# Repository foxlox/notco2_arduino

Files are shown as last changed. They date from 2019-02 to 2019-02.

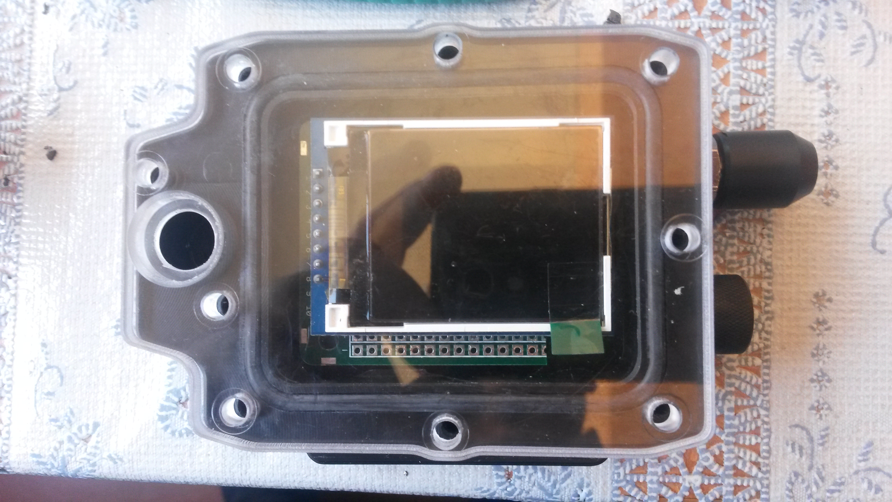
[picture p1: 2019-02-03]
docs/zzz_pics/wrist_enclosure_Sebastiano.jpg

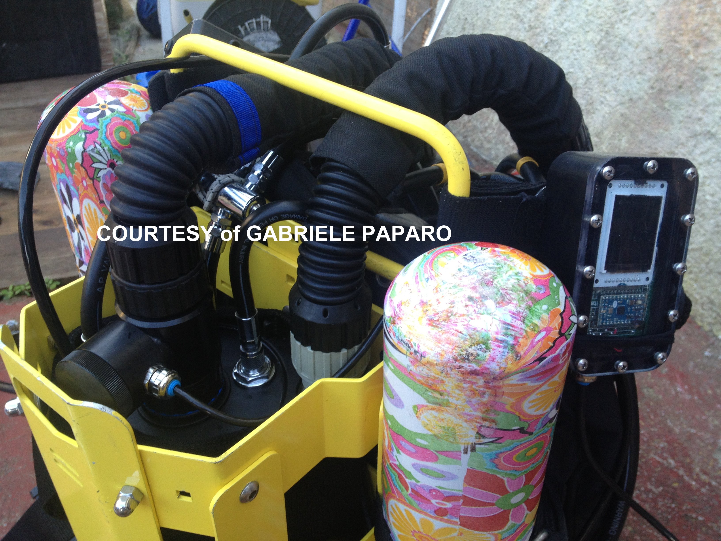
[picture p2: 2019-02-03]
docs/zzz_pics/photo(2).jpg

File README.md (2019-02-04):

NotCO2 - A Co2 analyzer for rebreathers
=======================================
fortunato lodari - fox@thebrain.net

If you wish to write me by email, please use the tag [NOTCO2] (with brackets)
in your subject

Please read all DOCs carefully

Project borns in 2011 by a personal need, I'm a mathematical, then I can't leave an independent variable to change my life for a sport.
This independent variable is Carbon Dioxide, CO2. Then I decided to begin a new project to analyze my breathe underwater.

Till today, me and other many peoples are using it with satisfaction by over 6 years.
The sensor is working good for an average life of 5 years.

I received a lot of offers for my project, but I wish to share this with other peoples who want to hack.

Please do not be surprised reading the source code, I'm really (but really!) much more professional and tidy
than you consider me to look at it, it's really simple. It was born to hack, and then when it worked 100% I left it as it is.

It bores me to refine it and I'll not do it just now
that I want to share it ;-)
Now it's your time to refine it, but remember: it really works very well!!!

Documents:

a. layout of PCB and project to build it

b. required hardware components

c. source code HUD (never optimized, discreetly legible, absolutely improvable...)

d. source code Wrist Console (also fot it never optimized, discreetly legible, absolutely improvable...)

e. all DGWs to build your own enclosures with a 3d lathe machine

f. some pics

About CO2 Sensor: I cannot include device's interface specification without owner authorization, but you could try to ask
them: Dynament Ltd - www.dynament.com

  The sensor doesn't suffer with moisture, it's important to stay face down in the loop, and to be dry after diving.

Please, read ALL documents in each folder.

The Author is not responsible for damage to peoples that use this project.
It works perfectly but you must build it perfectly too.

Special thanks to:

Gabriele Paparo for hints, support and test

Martin Tolksdorf for enclosure and wrist project

Domenico Tripodi for support and experience during  diving tests

Saverio Rotella for HUD testing

Massimilaino Salvatori for hints

Sebastiano Pappalardo and Paolo Li Pera of Grade Equipments for HUD, wrist console and sensors enclosures

Gian Ameri for hints and support

Aldo Ferrucci for support

Franco Amadeo for diving support

My wonderful wife Mara for everything!

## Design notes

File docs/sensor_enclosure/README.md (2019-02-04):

This is the project(DWGs) to build your own sensor enclosure.
This is for Buddy Inspiration, but the principle is the same for all!

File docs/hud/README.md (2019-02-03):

Hud with 8 leds

you need:

a. nr 2 Cable Glands about 12 Euro

	https://www.tecme.de/bilder/D0020.jpg

b. sensor enclosure for your own rebreather(buy from www.Tecme.DE, ask for Martin is a friend! He knows) about 150 Euro

	http://www.notco2.com/index.php/a-cosa-serve/32-uncategorised/65-enclosures

c. electronic enclosure (buy from Sebastiano Pappalardo Catania (CT), graderebequipments@libero.it, also he's a friend! He knows) about 150 Euro

	http://www.notco2.com/images/stories/virtuemart/product/100_4756.jpg

d. nr 1 magnetic reed bulb about 1 Euro

	https://www.ebay.com/itm/10-PEZZI-Rele-Reed-ad-ampolla-contatto-magnetico-effetto-hall-arduino-27mm-/222032990459

e. Main PCB about 50 Euro for 10 pieces

	see detailed instructions in mainpcb/ folder

f. nr 1 Arduino mini 5v about 6 Euro

	https://www.banggood.com/it/Wholesale-New-Ver-Pro-Mini-ATMEGA328-328p-5V-16MHz-Arduino-Compatible-Nano-Size-p-68534.html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

g. a lithium 3,7v 1400 mah battery about 10 Euro

	https://www.adafruit.com/product/2011

h. a little buzzer about 1 Euro

	https://www.distrelec.it/it/electromagnetic-buzzer-continuo-85-db-30-ma-vdc-rnd-components-rnd-430-00008/p/30117363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

i. 2 mt anti-cut cable, at least 6 poles about 50 Euro

	www.tecme.de

	Product code D0010

l. CO2 sensor by dynament about 160 Euro

	https://www.dynament.com/products/gas-sensors/premier-ex-certified-sensors/

	product code MSH-P/HCO2/5/V/P 0-100% VOL. CO2=0.4-2.0V Measurement step 0.01

m. Sensor connector by dynament about 5 Euro

	product code P/PCB

n. nr 1 eight led module about 2 Euro

	https://www.banggood.com/it/Duinopeak-8-Bit-WS2812-5050-RGB-LED-Smart-Full-Color-LED-Display-Module-Board-For-Arduino-p-1329241.html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

o. led module enclosure (Ask to Martin or Sebastiano) about 50 Euro

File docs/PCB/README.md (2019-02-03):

PCB information:
this is the project to build a PCB for NotCo2

Open with Eagles PCB. This release hasn't space for buzzer, could you insert it by yourself on arduino pin 3

connections:

SV2 pin 3, v+ in to battery v+

SV2 pin 1, v- -> to reed bulb -> to battery v-

SV2 pin 5, sensor tx

SV2 pin 6, sensor rx

Display

SV1 pin 1 TFT display VIN

SV1 pin 2 TFT display Ground

SV1 pin 3 RST

SV1 pin 4 RS

SV1 pin 5 SDA

SV1 pin 6 SDL

SV1 pin 7 CS

SV1 pin 8 TFT display VD33

HUD

SV2 pin 4, DIN

SV2 pin 3, led module v+

SV5 pin 2, led module v-

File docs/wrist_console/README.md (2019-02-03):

Wrist console

you need:

a. ITDB02-1.8SP 1.8" Arduino TFT LCD Display Module Shield Kit about 17 Euro

	https://www.boxelectronica.com/en/lcd/1178-itdb02-18sp-18-arduino-tft-lcd-display-module-shield-kit-for-starter.html

b. nr 2 Cable Glands about 12 Euro

	https://www.tecme.de/bilder/D0020.jpg

c. sensor enclosure for your own rebreather (buy from www.Tecme.DE, ask for Martin is a friend! He knows)  about 150 Euro

	http://www.notco2.com/index.php/a-cosa-serve/32-uncategorised/65-enclosures

d. electronic enclosure (buy from Sebastiano Pappalardo Catania (CT), graderebequipments@libero.it, also he's a friend! He knows)  about 150 Euro

	http://www.notco2.com/images/stories/10996812_913909068633336_3445941136974802208_o.jpg

e. nr 1 magnetic reed bulb about 1 Euro

	https://www.ebay.com/itm/10-PEZZI-Rele-Reed-ad-ampolla-contatto-magnetico-effetto-hall-arduino-27mm-/222032990459

f. Main PCB about 50 Euro for 10 pieces

	see detailed instructions in mainpcb/ folder

g. nr 1 Arduino mini 5v about 6 Euro

	https://www.banggood.com/it/Wholesale-New-Ver-Pro-Mini-ATMEGA328-328p-5V-16MHz-Arduino-Compatible-Nano-Size-p-68534.html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

h. a lithium 3,7v 1400 mah battery about 10 Euro

	https://www.adafruit.com/product/2011

i. a little buzzer about 1 Euro

	https://www.distrelec.it/it/electromagnetic-buzzer-continuo-85-db-30-ma-vdc-rnd-components-rnd-430-00008/p/30117363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

l. 2 mt anti-cut cable, at least 6 poles about 50 Euro

	www.tecme.de

	Product code D0010

m. CO2 sensor by dynament about 160 Euro

	https://www.dynament.com/products/gas-sensors/premier-ex-certified-sensors/

	product code MSH-P/HCO2/5/V/P 0-100% VOL. CO2=0.4-2.0V Measurement step 0.01

n. Sensor connector by dynament about 5 Euro

	product code P/PCB

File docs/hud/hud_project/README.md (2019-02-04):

HUD dwgs

attached dwg files for project are for 3 leds space, you could enlarge it

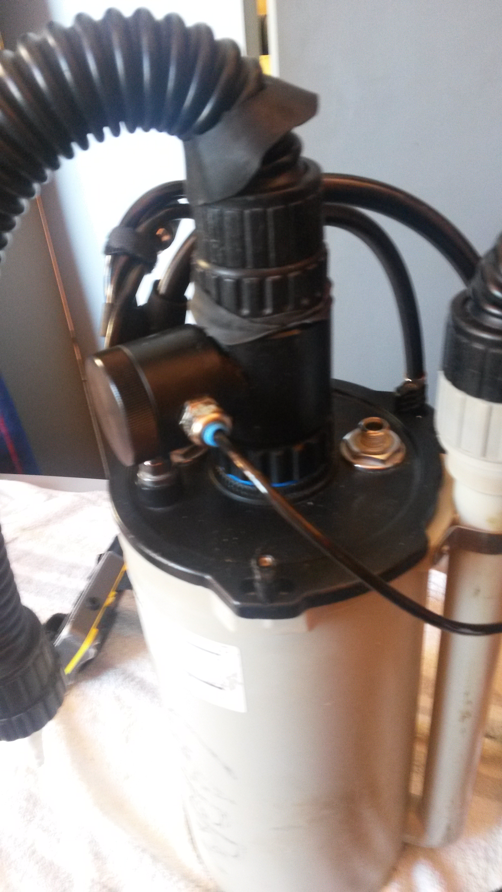
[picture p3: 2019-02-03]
docs/zzz_pics/2014-04-09 15.56.55.jpg

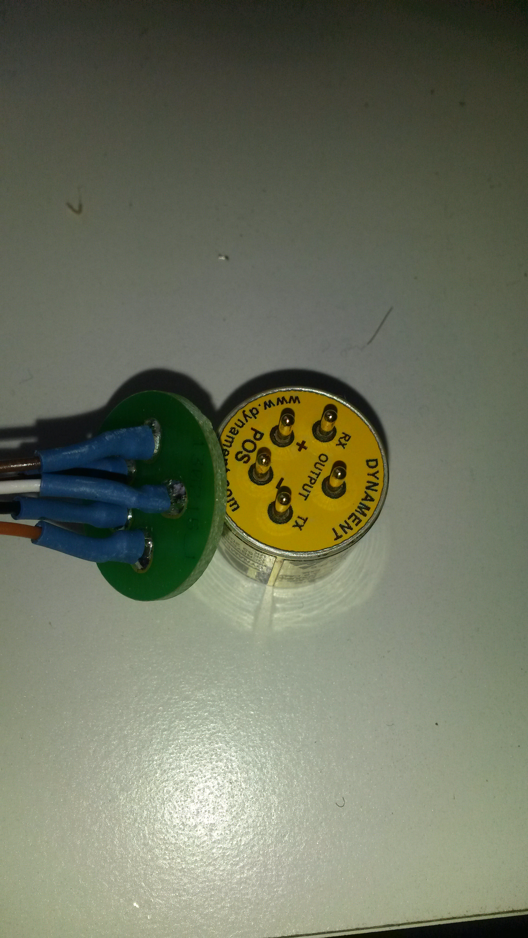
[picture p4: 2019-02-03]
docs/zzz_pics/sensor_with_PCB_2.jpg

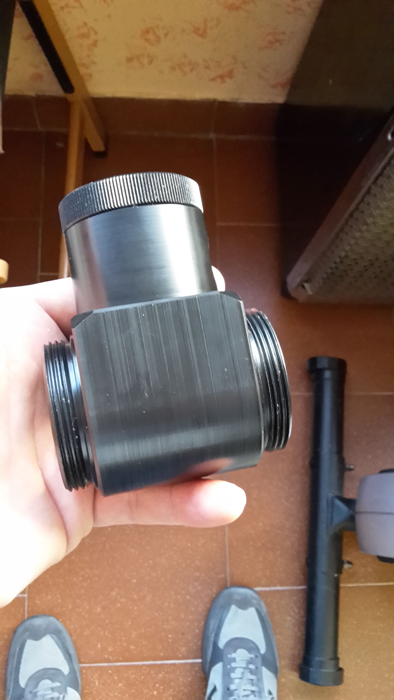
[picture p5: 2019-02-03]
docs/zzz_pics/universal_sensor_enclosure_tecme.jpg

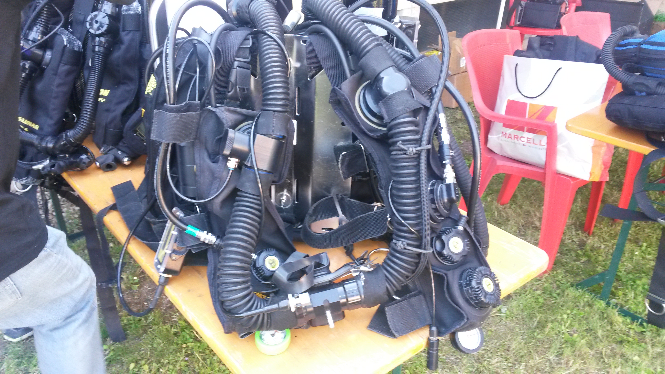
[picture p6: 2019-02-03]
docs/zzz_pics/big_meg_with_notco2.jpg

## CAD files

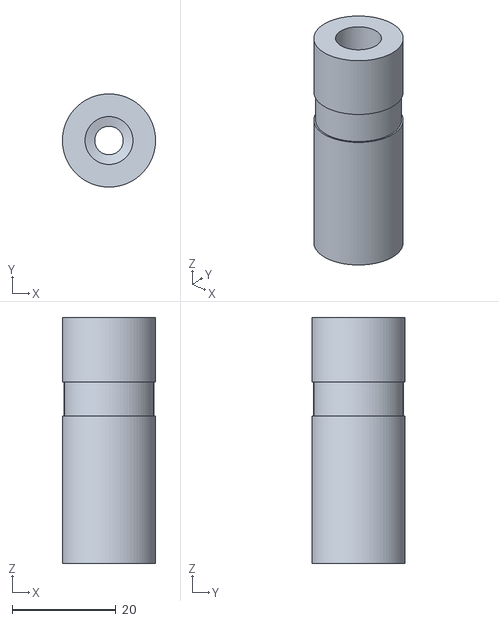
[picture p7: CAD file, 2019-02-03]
docs/hud/hud_project/hud3.stl
18.0 x 18.0 x 47.5

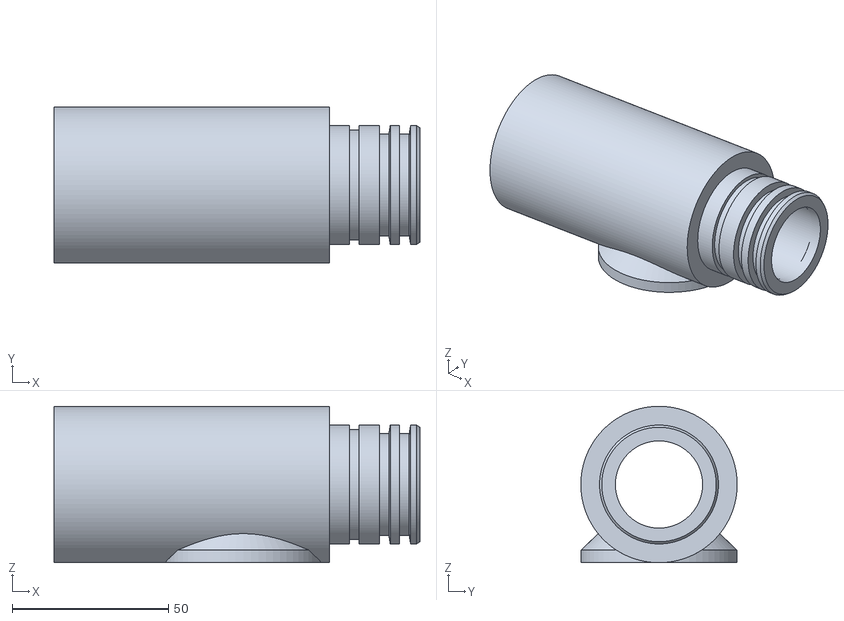
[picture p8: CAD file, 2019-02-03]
docs/sensor_enclosure/sensor_enclosure_project_for_inspiration/lungo_2_enclosure.stl
117.0 x 50.0 x 50.0

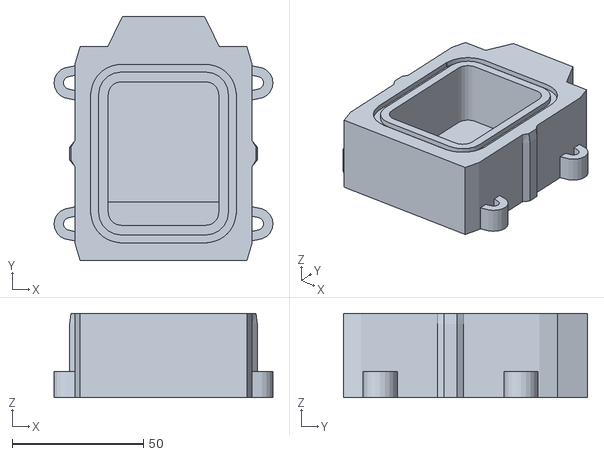
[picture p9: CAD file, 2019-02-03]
docs/wrist_console/console_project/console.stl
83.4 x 93.0 x 32.0

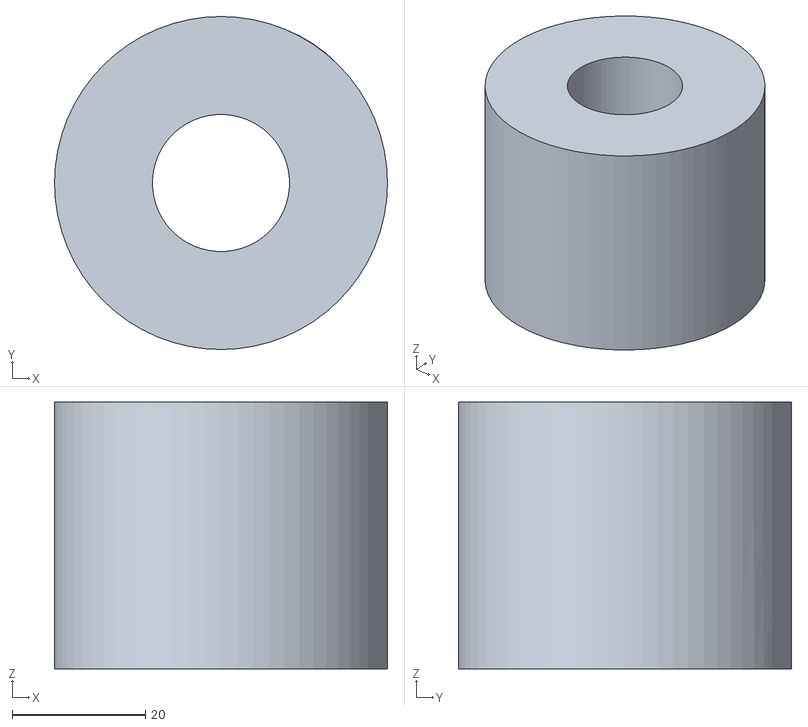
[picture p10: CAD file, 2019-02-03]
docs/sensor_enclosure/sensor_enclosure_project_for_inspiration/corto_1_enclosure.stl
50.0 x 50.0 x 40.0

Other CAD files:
docs/sensor_enclosure/sensor_enclosure_project_for_inspiration/enclosure_3d.dwg
docs/wrist_console/console_project/console_vista_2.dwg
docs/hud/hud_project/hud_sezione.dwg
docs/hud/hud_project/hud3_3d.dwg
docs/sensor_enclosure/sensor_enclosure_project_for_inspiration/enclosure_VISTA_2.dwg
docs/wrist_console/console_project/console_vista_3d.dwg
docs/hud/hud_project/prospetto.dwg
docs/wrist_console/console_project/console_sezione2.dwg
docs/sensor_enclosure/sensor_enclosure_project_for_inspiration/enclosure_VISTA_3.dwg
docs/wrist_console/console_project/console_sezione1.dwg
docs/sensor_enclosure/sensor_enclosure_project_for_inspiration/sezione_enclosure.dwg

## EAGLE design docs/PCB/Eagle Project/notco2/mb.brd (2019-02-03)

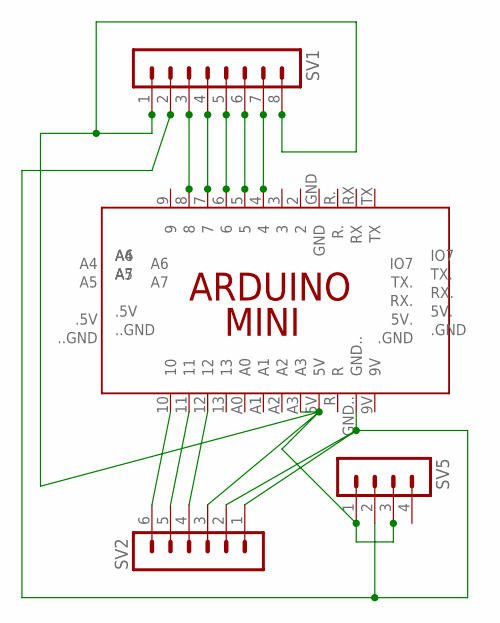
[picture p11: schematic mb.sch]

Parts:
PCB2: ARDUINO_MINI
SV1: MA08-1W
SV2: MA06-1
SV5: MA04-1

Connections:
unnamed: PCB2.8, SV1.3
unnamed: PCB2.7, SV1.4
unnamed: PCB2.6, SV1.5
unnamed: PCB2.5, SV1.6
unnamed: PCB2.4, SV1.7
unnamed: PCB2.5V, PCB2.A3, SV1.1, SV1.8, SV2.3, SV5.1, SV5.3
unnamed: PCB2.12, SV2.4
unnamed: PCB2.GND.., SV1.2, SV2.1, SV2.2, SV5.2
unnamed: PCB2.11, SV2.5
unnamed: PCB2.10, SV2.6

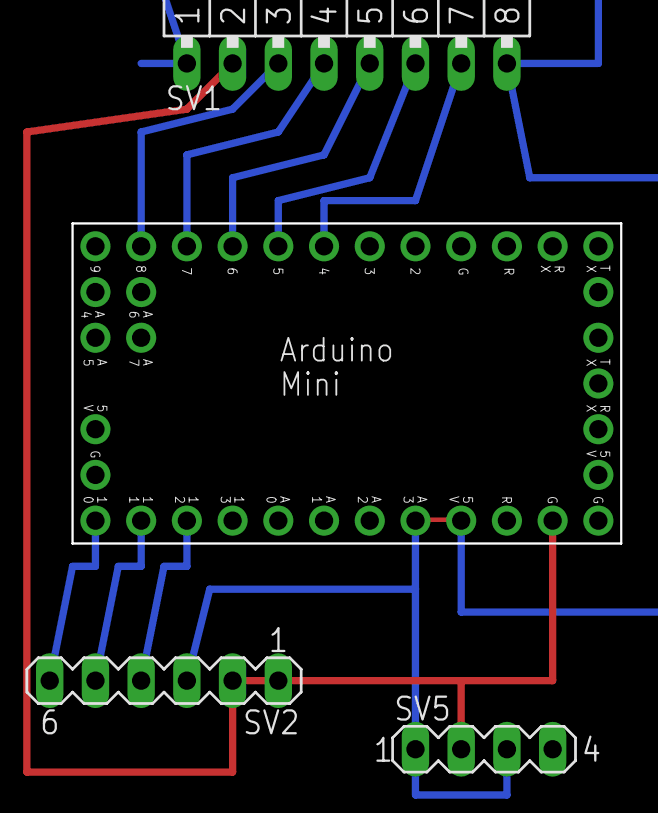
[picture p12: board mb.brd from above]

Board: 2 copper layers, 4 parts (0 on the bottom side), 10 nets.

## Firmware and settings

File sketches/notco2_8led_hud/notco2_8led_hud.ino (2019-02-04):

/*************************************************** 
  This is a real time CO2 reader for Arduino. 
  Written by Fortunato Lodari.  
  Apache 2 license, all text above must be included 
  in any redistribution.
  
  Copyright 2019 fortunato lodari fox@thebrain.net

   Licensed under the Apache License, Version 2.0 (the "License");
   you may not use this file except in compliance with the License.
   You may obtain a copy of the License at

       http://www.apache.org/licenses/LICENSE-2.0

   Unless required by applicable law or agreed to in writing, software
   distributed under the License is distributed on an "AS IS" BASIS,
   WITHOUT WARRANTIES OR CONDITIONS OF ANY KIND, either express or implied.
   See the License for the specific language governing permissions and
   limitations under the License.
  
 ****************************************************/


#include <Wire.h>
#include <avr/power.h>
#include "SoftwareSerial.h"
#include "FastLED.h"
#define NUM_LEDS 8
#define DATA_PIN 12
CRGB leds[NUM_LEDS];

#include <SPI.h>


SoftwareSerial K_30_Serial(10,12);  //Sets up a virtual serial port


byte readCO2[] = {0x10, 0x13, 0x01, 0x10, 0x1F, 0x00, 0x53};
                
//byte readCO2[] = {0x10, 0x13, 0x01, 0x10, 0x1F, 0x00, 0x53};  //Command packet to read Co2 (see app note)
//byte readCO2[] = {0x10, 0x13, 0x06, 0x10, 0x1F, 0x00, 0x58};
byte response[] = {0,0,0,0,0,0,0,0,0};  //create an array to store the response
const int buzzerPin =  3;


void setup() 
{

FastLED.addLeds<NEOPIXEL, DATA_PIN>(leds, NUM_LEDS);
  pinMode(buzzerPin, OUTPUT);
  //pinMode(onPin, OUTPUT);     
  Serial.begin(9600);
  Serial.print("INIT");
  digitalWrite(buzzerPin, HIGH);
  Wire.begin();
  digitalWrite(buzzerPin, LOW);
  delay(2000);
  digitalWrite(buzzerPin, LOW);
  delay(500);
  digitalWrite(buzzerPin,HIGH);
  delay(500);
  digitalWrite(buzzerPin,LOW);
  K_30_Serial.begin(38400);    //Opens the virtual serial port with a baud of 38400

Kwrite(readCO2);


}


float co2perc,tcoC, pressure, atm, tcoI, signal, voltage;
long uptime=0,olduptime=0;


void loop() 
{
 int i=0,k=0,ttt;
 char myHexString[10],myHexString2[10];

 
 byte a;
 Kwrite(readCO2);
 a=K_30_Serial.read();
 Serial.print("0x");
 Serial.print(a,HEX);
 Serial.print(" "); 
 i=0;

  while(K_30_Serial.available())  //flush whatever we have
    {
           
     int sensorValue = analogRead(A3);
     Serial.print("sensorv    ");
     Serial.println(sensorValue);
     voltage = sensorValue* (3.7 / 1023);
     Serial.print("voltage    ------------------1-");
     Serial.println(voltage,2);
     i++;
     byte b=a;
     a=K_30_Serial.read();
     if ((b==0x10)&&(a==0x19))
      Serial.println("NACK--------------------------NACK");
             
     if ((b==0x10)&&(a==0x1A))
      {
//-----               Serial.println("DLE DAT ------");
       int dlen=K_30_Serial.read();
       Serial.print("----------DataLEN ");
       Serial.println(dlen);
       int z=0;
       a=K_30_Serial.read();
            
       while (z<dlen-1)
        {
         b=a;
         if ((b==0x10)&&(b==a))
         a=K_30_Serial.read();
         if (z==3)
          {
           Serial.print("co2 % ");
           co2perc=prendi4();
           z+=4;
          }

         if (z==7)
          {
           Serial.print("temp ");
           tcoI=prendi4()*0.55;
           z+=4;
          }

         if (z==511)
           {
            Serial.print("dtr: ");
            signal=prendi2();
            Serial.println(signal);
            z+=2;
           }
////?dopotemplow
         if (z==513)
           {
            Serial.print("ref: ");
            long dethigh=prendi2();
            Serial.println(dethigh);
            z+=2;
           }
                  
          if (z==15)
           {
            Serial.println("in z");          
            int st=0;
            for (int t = 0; t < 4; t++) 
             {
              a=K_30_Serial.read();
              b=a;
              if ((b==0x10)&&(b==a))
               a=K_30_Serial.read();
//-----    Serial.print(a,HEX);
              myHexString[0+st] = (a >> 4) + 0x30;
               if (myHexString[0+st] > 0x39) myHexString[0+st] +=7;
              myHexString[1+st] = (a & 0x0f) + 0x30;
              if (myHexString[1+st] > 0x39) myHexString[1+st] +=7;
               st+=2;
//-----    Serial.print("v: ");
//-----    Serial.println(a,HEX);
               z++;
             }
            }   
           if ((z==19)&&(dlen==32))
            {
             Serial.print("CO2 HEX: ");
             myHexString2[0]=myHexString[6];
             myHexString2[1]=myHexString[7];
             myHexString2[2]=myHexString[4];
             myHexString2[3]=myHexString[5];
             myHexString2[4]=myHexString[2];
             myHexString2[5]=myHexString[3];
             myHexString2[6]=myHexString[0];
             myHexString2[7]=myHexString[1];
             char zerox[11]="0x";
             for (int j=0;j<8;j++)
              zerox[j+2]=myHexString2[j];
                  //-----  Serial.println(zerox); 
             long val = 0;
             val=strtoul(zerox,0,16);
//-----Serial.println(val);   
             stampanum(zerox);
             ttt=0;
            }
           if (z==19)
            {
             Serial.print("uptime: ");
             uptime=prendi4();
             z+=4;
            }
                  
//dtr low  
           if (z==2223)
            {
             Serial.print("dtrl: ");
             long detlow=prendi2();
             Serial.println(detlow);
             z+=2;
            }
                    
                   
////dethig
           if (z==2225)
            {
             Serial.print("dtrh: ");
             long dethigh=prendi2();
             Serial.println(dethigh);
             z+=2;
            }

////reflow
           if (z==2227)
            {
             Serial.print("refl: ");
             long reflow=prendi2();
             Serial.println(reflow);
             z+=2;
            }
////refhig
           if (z==2229)
            {
             Serial.print("refh: ");
             long refhigh=prendi2();
             Serial.println(refhigh);
             z+=2;
            }
 
           a=K_30_Serial.read();
              
           if ((b==0x10)&&(a==0x10))
            {
//-----                      Serial.println("SNOOP IN DLEN");
            }
           else
            z++;
           }//aaa
          //fine while dlen               
          //Serial.print(a);
         Serial.println(" fine DATA");
         Serial.println();
               
         Kwrite(readCO2);
         delay(500); //era 500
         int in=0;
//-----            Serial.println("in while cerca EOF");
         int ff=0;
         while (((b != 0x10)&&(a != 0x1F))||(ff>4))
             {
               in++;
               b=a;
               a=K_30_Serial.read();
               if ((b==0x10)&&(a==0x10))
                {
                  b=a;
                  a=K_30_Serial.read();
                }       
               if (a==0xFF)
                {
                  ff++;
//-----                  if (ff>3)
//-----                   Serial.println("breakato!");
                }
             } 
             
           //fine while cerca EOF
           a=K_30_Serial.read();
           int crc=K_30_Serial.read();
        }           
      }
}

float prendi4()
{
 char dtrh[11];
 int st=0;
 for(int ud=0;ud<4;ud++)
  {
   byte a=K_30_Serial.read();
   char b=a;
   if ((b==0x10)&&(b==a))
    a=K_30_Serial.read();
   dtrh[0+st] = (a >> 4) + 0x30;
   if (dtrh[0+st] > 0x39) dtrh[0+st] +=7;
    dtrh[1+st] = (a & 0x0f) + 0x30;
   if (dtrh[1+st] > 0x39) dtrh[1+st] +=7;
    st+=2;
  }
 char a2[11];
 a2[0]='0'; a2[1]='x'; a2[2]=dtrh[6]; a2[3]=dtrh[7]; a2[4]=dtrh[4]; a2[5]=dtrh[5]; a2[6]=dtrh[2]; a2[7]=dtrh[3]; a2[8]=dtrh[0]; a2[9]=dtrh[1];
 union
  {
   long a;
   byte b [4];
   float f;  
  } t;
    
 t.a=strtoul(a2,0,16);
 Serial.println(t.f);
 return (t.f);
}


long prendi2()
{
 char dtrh[8];
 int st=0;
 for(int ud=0;ud<2;ud++)
  {
   byte a=K_30_Serial.read();
   char b=a;
   if ((b==0x10)&&(b==a))
    a=K_30_Serial.read();
   dtrh[0+st] = (a >> 4) + 0x30;
   if (dtrh[0+st] > 0x39) dtrh[0+st] +=7;
   dtrh[1+st] = (a & 0x0f) + 0x30;
   if (dtrh[1+st] > 0x39) dtrh[1+st] +=7;
   st+=2;
  }
 char a2[10];
 a2[0]='0'; a2[1]='x'; a2[6]=dtrh[2]; a2[7]=dtrh[3]; a2[8]=dtrh[0]; a2[9]=dtrh[1]; a2[2]='0'; a2[3]='0'; a2[4]='0'; a2[5]='0';
 return strtoul(a2,0,16);
}

void suona(int pin, int dlay)
{
 digitalWrite(pin,HIGH);
 delay(dlay);
 digitalWrite(pin,LOW);
}

float min=0,max=0,conta=1;
void stampanum(char c[11])
{
  int red,i;
  
  union
    {
     long a;
    byte b [4];
    float f;  
    } tco;
    
   long val = 0;
   val=strtoul(c,0,16);
  
  tco.a = val;
  tco.f=abs(tco.f);
  Serial.println(c);
  float pco2=co2perc;
  digitalWrite(buzzerPin,LOW);

//////////iniled

if (uptime>30) //time for sensor to boot
{
  int led = pco2*100  ;
  Serial.print("led: ");
  Serial.println(led);
  int ik; 
  for (i=0;i<8;i++)
   leds[i] = CRGB::Black;
  FastLED.show();
  delay(100);
  ///uptime<1
  if (pco2==0.00)
   {
     leds[0] = CRGB::Green;
   }


  if ((pco2>0)&&(pco2<0.09))
   {

    for (ik=0;ik<=led;ik++)
     {
      if (led<4)
       leds[ik] = CRGB::Green;
      if ((led>=4)&&(led<6))
       leds[ik] = CRGB::Yellow;
      if (led>=6)
       leds[ik] = CRGB::Red;  
     }
   }
   
 if ((pco2>0.03)&&(pco2<=0.05))
  suona(buzzerPin,200);
  
 if ((pco2>=0.09)&&(pco2<0.16))
  {
    //int index = led - 8;
    for (ik=0;ik<(led-8);ik++)
     {
       leds[(led-8)-ik] = CRGB::Red;
     }
     leds[0]=CRGB::Blue;   
  }
 if (pco2>=0.16)
  {
    leds[0] = CRGB::Blue;
    leds[1] = CRGB::Blue;
    leds[2] = CRGB::Red;
    leds[3] = CRGB::Red;
    leds[4] = CRGB::Red;
    leds[5] = CRGB::Red;
    leds[6] = CRGB::Red;
    leds[7] = CRGB::Red;

  }

 if (pco2>0.05)
  suona(buzzerPin,300);
 FastLED.show();
}
else
{
  int ik;
  for (ik=0;ik<9;ik++)
   {
     leds[ik] = CRGB::Blue;
     delay(100);
     FastLED.show();
   }
    for (ik=0;ik<9;ik++)
   {
     leds[ik] = CRGB::Black;
     delay(100);
     FastLED.show();
   }

}
//////////endled


if (pco2>=0.50)
 {
   red=1;
      digitalWrite(buzzerPin,HIGH);
 }


 if (tco.f>0.25)
  digitalWrite(buzzerPin,HIGH);
 else
  digitalWrite(buzzerPin,LOW);

  Serial.print ("valore CO2: ");
  if ((max<tco.f)&&(tco.f<3))
   max=tco.f;
  if (tco.f>0)
   {
     min+=tco.f;
     conta++;
   }
  Serial.println (tco.f,4);
  //delay(500);
}




void Kwrite(byte pkt[])
{
 for (int k=0; k<7; k++)
  K_30_Serial.write(readCO2[k]);
}
